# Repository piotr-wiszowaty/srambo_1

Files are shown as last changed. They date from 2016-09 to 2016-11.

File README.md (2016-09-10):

srambo\_1
========

srambo\_1 is a yet another 320 kB [Atari](https://en.wikipedia.org/wiki/Atari_8-bit_family) XE memory expansion. It designed for
Atari 130 XEs and 65 XEs with ECI connector.

Description
-----------

The device has two modes of operation (selected with a jumper):

1. 'Rambo' - extended memory banks are selected with PORTB bits 2, 3, 5, 6.
   Access to extended memory by both CPU and ANTIC is controlled with PORTB
   bit 4.
   To turn on this mode one needs to connect pins AUX3 and AUX4 together.
2. 'Compy' - extended memory banks are selected with PORTB bits 2, 3, 6, 7.
   Access to extended memory by CPU is controlled with PORTB bit 4. Access to
   extended memory by ANTIC is controlled with PORTB bit 5.
   To select this mode one needs to connect pins AUX3 and AUX2 together.

Sources
-------

`cpld/` - CPLD design files (ISE WebPack 14.7)

`pcb/`  - PCB design files (Kicad 4.0.3)

Installation
------------

All Atari modifications are easily reversible (provided one does not - for
example - destroy any tracks during desoldering process).
To install the expansion one needs to:

0. Assemble the memory expansion (obviously)
1. Desolder all DRAM chips (U9..U16, U26..U33)
2. Desolder MMU chip (U34)
3. Desolder EMMU chip U3 (130 XE) or three wire jumpers (65 XE)
4. Solder a wire between U23 PIA pin 16 and U3 EMMU pin 12
5. Solder appropriate pin-header sockets into the motherboard (see PCB design
   files for reference)
6. Plug the assembled device into the sockets

References
----------

Various parts of control logic are based on [576 kB memory expansion](http://atarionline.pl/v01/index.php?id=1235583828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) by ASAL.

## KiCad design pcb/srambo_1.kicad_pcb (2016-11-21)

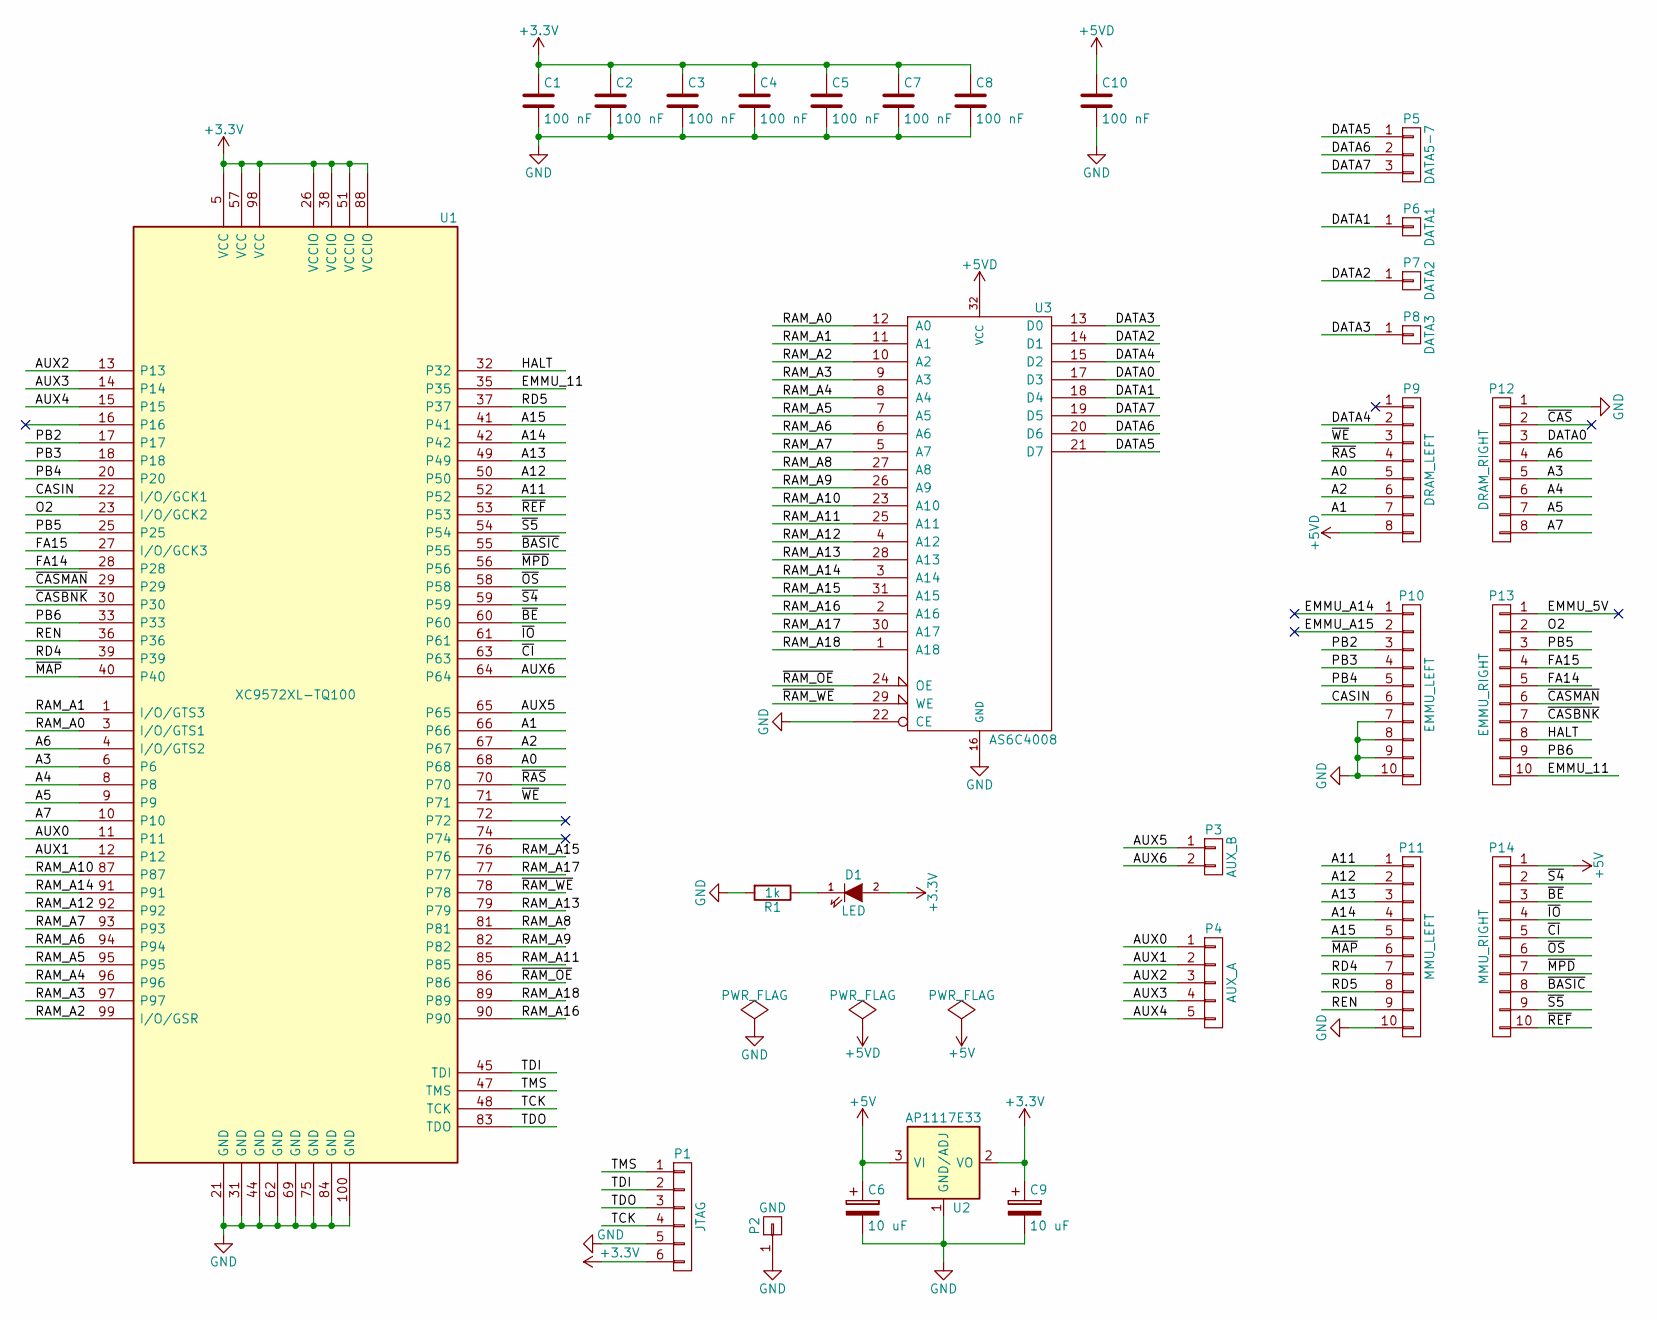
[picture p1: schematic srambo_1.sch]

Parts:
C1, C2, C3, C4, C5, C7, C8, C10: 100 nF; C_0805_HandSoldering
C6, C9: 10 uF; TantalC_SizeB_EIA-3528_HandSoldering
D1: LED; LED_0805
P1: JTAG; Pin_Header_Straight_1x06
P2: GND; Pin_Header_Straight_1x01
P3: AUX_B; Pin_Header_Straight_1x02
P4: AUX_A; Pin_Header_Straight_1x05
P5: DATA5-7; Pin_Header_Straight_1x03
P6: DATA1; Pin_Header_Straight_1x01
P7: DATA2; Pin_Header_Straight_1x01
P8: DATA3; Pin_Header_Straight_1x01
P9: DRAM_LEFT; Pin_Header_Straight_1x08
P10: EMMU_LEFT; Pin_Header_Straight_1x10
P11: MMU_LEFT; Pin_Header_Straight_1x10
P12: DRAM_RIGHT; Pin_Header_Straight_1x08
P13: EMMU_RIGHT; Pin_Header_Straight_1x10
P14: MMU_RIGHT; Pin_Header_Straight_1x10
R1: 1k; R_0805_HandSoldering
U1: XC9572XL-TQ100; TQFP-100_14x14mm_Pitch0.5mm
U2: AP1117E33; TO-252-2Lead
U3: AS6C4008; TSOP-II-32_21.0x10.2mm_Pitch1.27mm

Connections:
+3V3: C1.1, C2.1, C3.1, C4.1, C5.1, C7.1, C8.1, C9.1, D1.2 (A), P1.6, U1.5 (VCC), U1.26 (VCCIO), U1.38 (VCCIO), U1.51 (VCCIO), U1.57 (VCC), U1.88 (VCCIO), U1.98 (VCC), U2.2 (VO)
+5V: C6.1, P14.1, U2.3 (VI)
+5VD: C10.1, P9.8, U3.32 (VCC)
/A0: P9.5, U1.68
/A1: P9.7, U1.66
/A2: P9.6, U1.67
/A3: P12.5, U1.6
/A4: P12.6, U1.8
/A5: P12.7, U1.9
/A6: P12.4, U1.4 (I/O/GTS2)
/A7: P12.8, U1.10
/A11: P11.1, U1.52
/A12: P11.2, U1.50
/A13: P11.3, U1.49
/A14: P11.4, U1.42
/A15: P11.5, U1.41
/AUX0: P4.1, U1.11
/AUX1: P4.2, U1.12
/AUX2: P4.3, U1.13
/AUX3: P4.4, U1.14
/AUX4: P4.5, U1.15
/AUX5: P3.1, U1.65
/AUX6: P3.2, U1.64
/CASIN: P10.6, U1.22 (I/O/GCK1)
/DATA0: P12.3, U3.17 (D3)
/DATA1: P6.1, U3.18 (D4)
/DATA2: P7.1, U3.14 (D1)
/DATA3: P8.1, U3.13 (D0)
/DATA4: P9.2, U3.15 (D2)
/DATA5: P5.1, U3.21 (D7)
/DATA6: P5.2, U3.20 (D6)
/DATA7: P5.3, U3.19 (D5)
/EMMU_5V: P13.1
/EMMU_11: P13.10, U1.35
/EMMU_A14: P10.1
/EMMU_A15: P10.2
/FA14: P13.5, U1.28
/FA15: P13.4, U1.27 (I/O/GCK3)
/HALT: P13.8, U1.32
/O2: P13.2, U1.23 (I/O/GCK2)
/PB2: P10.3, U1.17
/PB3: P10.4, U1.18
/PB4: P10.5, U1.20
/PB5: P13.3, U1.25
/PB6: P13.9, U1.33
/RAM_A0: U1.3 (I/O/GTS1), U3.12 (A0)
/RAM_A1: U1.1 (I/O/GTS3), U3.11 (A1)
/RAM_A2: U1.99 (I/O/GSR), U3.10 (A2)
/RAM_A3: U1.97, U3.9 (A3)
/RAM_A4: U1.96, U3.8 (A4)
/RAM_A5: U1.95, U3.7 (A5)
/RAM_A6: U1.94, U3.6 (A6)
/RAM_A7: U1.93, U3.5 (A7)
/RAM_A8: U1.81, U3.27 (A8)
/RAM_A9: U1.82, U3.26 (A9)
/RAM_A10: U1.87, U3.23 (A10)
/RAM_A11: U1.85, U3.25 (A11)
/RAM_A12: U1.92, U3.4 (A12)
/RAM_A13: U1.79, U3.28 (A13)
/RAM_A14: U1.91, U3.3 (A14)
/RAM_A15: U1.76, U3.31 (A15)
/RAM_A16: U1.90, U3.2 (A16)
/RAM_A17: U1.77, U3.30 (A17)
/RAM_A18: U1.89, U3.1 (A18)
/RD4: P11.7, U1.39
/RD5: P11.8, U1.37
/REN: P11.9, U1.36
/TCK: P1.4, U1.48 (TCK)
/TDI: P1.2, U1.45 (TDI)
/TDO: P1.3, U1.83 (TDO)
/TMS: P1.1, U1.47 (TMS)
/~BASIC: P14.8, U1.55
/~BE: P14.3, U1.60
/~CAS: P12.2
/~CASBNK: P13.7, U1.30
/~CASMAN: P13.6, U1.29
/~CI: P14.5, U1.63
/~IO: P14.4, U1.61
/~MAP: P11.6, U1.40
/~MPD: P14.7, U1.56
/~OS: P14.6, U1.58
/~RAM_OE: U1.86, U3.24 (OE)
/~RAM_WE: U1.78, U3.29 (WE)
/~RAS: P9.4, U1.70
/~REF: P14.10, U1.53
/~S4: P14.2, U1.59
/~S5: P14.9, U1.54
/~WE: P9.3, U1.71
GND: C1.2, C2.2, C3.2, C4.2, C5.2, C6.2, C7.2, C8.2, C9.2, C10.2, P1.5, P2.1, P10.7, P10.8, P10.9, P10.10, P11.10, P12.1, R1.2, U1.21 (GND), U1.31 (GND), U1.44 (GND), U1.62 (GND), U1.69 (GND), U1.75 (GND), U1.84 (GND), U1.100 (GND), U2.1 (GND/ADJ), U3.16 (GND), U3.22 (CE)
unnamed: D1.1 (K), R1.1

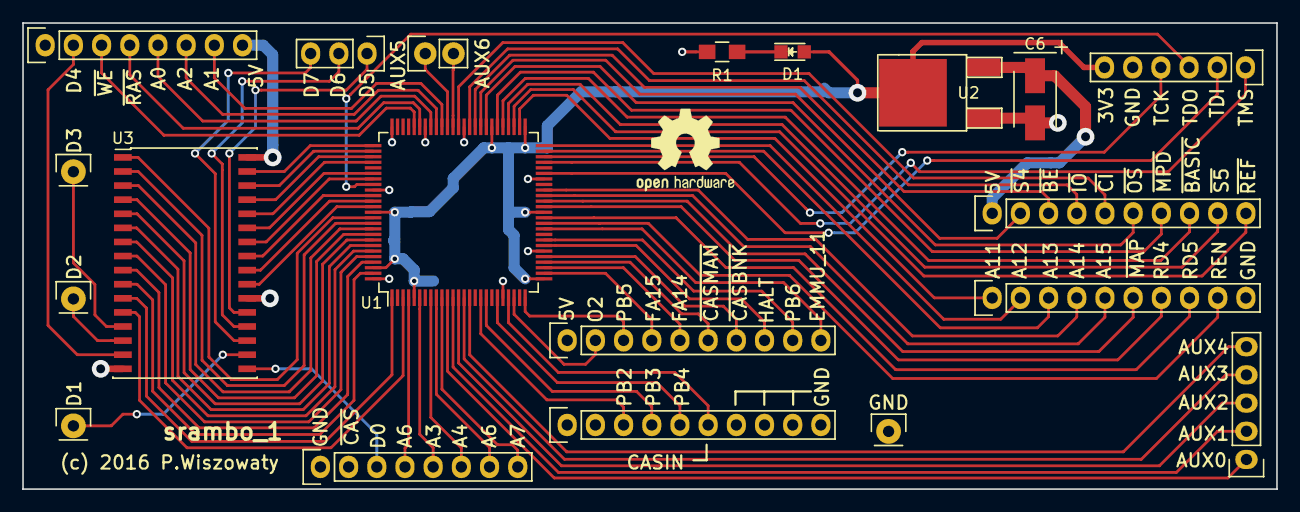
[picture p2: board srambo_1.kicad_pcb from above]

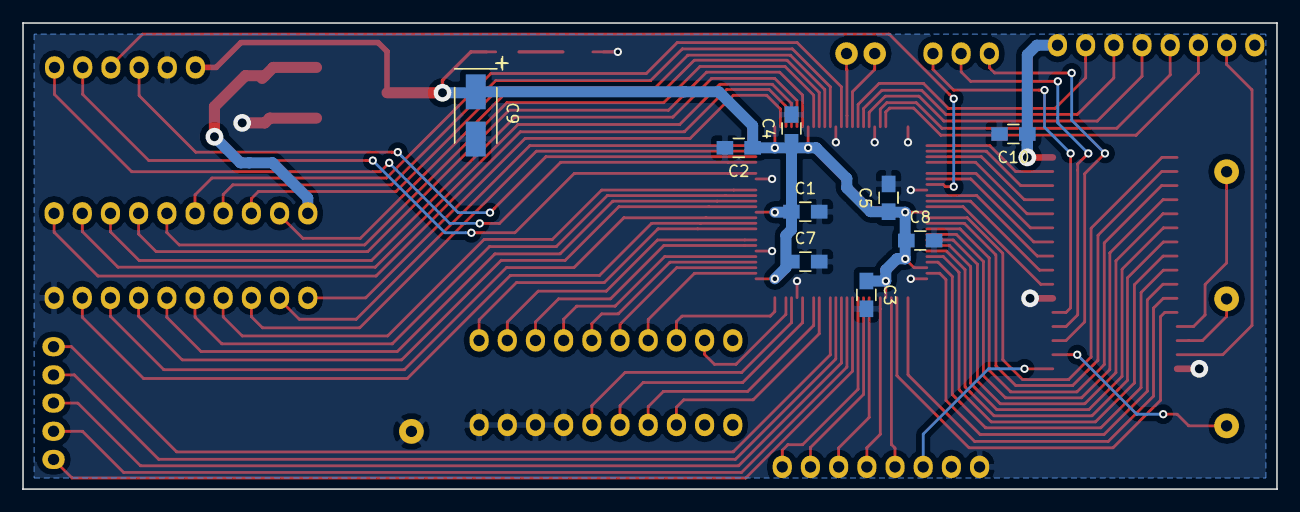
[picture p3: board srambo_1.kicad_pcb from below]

Board: 2 copper layers, 113.0 x 42.0 mm, 29 parts (9 on the bottom side), 86 nets.

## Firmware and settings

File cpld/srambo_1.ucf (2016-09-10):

net "aux0" loc = p11;
net "aux1" loc = p12;
net "aux2" loc = p13;
net "aux3" loc = p14;
net "aux4" loc = p15;
net "aux5" loc = p65;
net "aux6" loc = p64;

net "pb2" loc = p17;
net "pb3" loc = p18;
net "pb4" loc = p20;
net "pb5" loc = p25;
net "pb6" loc = p33;

net "casin" loc = p22;
net "o2" loc = p23;
net "fa14" loc = p28;
net "fa15" loc = p27;
net "n_map" loc = p40;
net "rd4" loc = p39;
net "rd5" loc = p37;
net "ren" loc = p36;
net "n_os" loc = p58;
net "n_ci" loc = p63;
net "n_io" loc = p61;
net "n_be" loc = p60;
net "n_s4" loc = p59;
net "n_s5" loc = p54;
net "n_mpd" loc = p56;
net "n_basic" loc = p55;
net "n_ref" loc = p53;
net "n_ras" loc = p70;
net "n_we" loc = p71;

net "casman" loc = p29;
net "casbnk" loc = p30;
net "emmu_11" loc = p35;
net "halt" loc = p32;

net "a0" loc = p68;
net "a1" loc = p66;
net "a2" loc = p67;
net "a3" loc = p6;
net "a4" loc = p8;
net "a5" loc = p9;
net "a6" loc = p4;
net "a7" loc = p10;
net "a11" loc = p52;
net "a12" loc = p50;
net "a13" loc = p49;
net "a14" loc = p42;
net "a15" loc = p41;

net "ram_addr<0>" loc = p3;
net "ram_addr<1>" loc = p1;
net "ram_addr<2>" loc = p99;
net "ram_addr<3>" loc = p97;
net "ram_addr<4>" loc = p96;
net "ram_addr<5>" loc = p95;
net "ram_addr<6>" loc = p94;
net "ram_addr<7>" loc = p93;
net "ram_addr<8>" loc = p81;
net "ram_addr<9>" loc = p82;
net "ram_addr<10>" loc = p87;
net "ram_addr<11>" loc = p85;
net "ram_addr<12>" loc = p92;
net "ram_addr<13>" loc = p79;
net "ram_addr<14>" loc = p91;
net "ram_addr<15>" loc = p76;
net "ram_addr<16>" loc = p90;
net "ram_addr<17>" loc = p77;
net "ram_addr<18>" loc = p89;
net "ram_n_we" loc = p78;
net "ram_n_oe" loc = p86;

NET "o2" BUFG = CLK;
NET "o2" TNM_NET = "grp_o2";
TIMESPEC "TS_o2" = PERIOD "grp_o2" 561 ns HIGH 40%;
NET "pb5" BUFG = DATA_GATE;

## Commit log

2016-09-10 Add sources
    [srambo_1.kicad_pcb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]
2016-11-21 PCB: Update symbols
    [srambo_1.sch]
2016-11-21 PCB: Add OSHW logo
    [srambo_1.kicad_pcb]

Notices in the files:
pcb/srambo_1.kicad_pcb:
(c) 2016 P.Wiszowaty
